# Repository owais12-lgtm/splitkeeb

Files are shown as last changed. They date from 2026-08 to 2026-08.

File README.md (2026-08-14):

This my 42 key wireless split keyboard! It follows the corne layout I believe with a 3x6+3 layout. It will use 42 switches and a screen, and is powered by a custom made rp2040 dev board.

# pictures 







# Features
- Dual-core M0+ processor
- Flexible clock running up to 133 MHz
- 264 kB of SRAM
- USB 1.1 controller and PHY with device and host support
- Low-power sleep and dormant modes
- Accurate clock and timer
- Accelerated floating-point libraries
- Temperature sensor
- Oled screen

# BOM 

| Name | Purpose | Quantity | Total Cost (USD) | Link | Distributor |
|---|---|---|---|---|---|
| PCB | PCB | 1 | $60.00 | [lioncircuits.com](https://www.lioncircuits.com/quote) | Lion Circuits |
| Keycaps | Keycaps | 1 | $30.00 | [curiositycaps.in](https://curiositycaps.in/products/polar-day-line-crack-side-backlit-cherry-keycaps) | Curiosity Caps |
| Akko V3 Silver | Switches | 2 | $32.00 | [stackskb.com](https://stackskb.com/store/akko-v3-silver-pro-switch-pack-of-45/) | StacksKB |
| OLED | OLED | 1 | $2.00 | [robu.in](https://robu.in/product/0-91-inch-128x32-i2c-iic-serial-blue-oled-lcd-display-module/) | Robu |

# CAD
https://www.tinkercad.com/things/a4B1lVT00vB-epic-allis-leelo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

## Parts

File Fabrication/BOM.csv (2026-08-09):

Id | Designator | Footprint | Quantity | Designation | Supplier and ref
1 | D33,D27,D26,D28,D24,D30,D32,D31,D23,D29,D25,D22,D29,D23,D30,D33,D24,D26,D27,D25,D32,D31,D28,D22 | LED_0201_0603Metric | 24 | LED
2 | C14,C13,C14,C13 | C_0402_1005Metric | 4 | 33pF
3 | C8,C7,C2,C12,C11,C17,C10,C5,C9,C6,C3,C7,C5,C9,C2,C8,C10,C12,C11,C6,C3,C17 | C_0402_1005Metric | 22 | 0.1uF
4 | SW29,SW41,SW28,SW39,SW35,SW34,SW40,SW37,SW43,SW27,SW30,SW24,SW33,SW23,SW36,SW38,SW31,SW42,SW25,SW32,SW26,SW8,SW20,SW12,SW19,SW5,SW3,SW18,SW7,SW11,SW14,SW13,SW4,SW21,SW17,SW6,SW2,SW10,SW15,SW16,SW1,SW9 | SW_Cherry_MX_1.00u_PCB | 42 | SW_Push_45deg
5 | U2,U2 | SOT-23 | 2 | MCP1700x-330xxTT
6 | C1,C4,C4,C1 | C_0402_1005Metric | 4 | 1uF
7 | C16,C15,C16,C15 | C_0603_1608Metric | 4 | 10uF
8 | R2,R1,R2,R1 | R_0402_1005Metric | 4 | 27
9 | U1,U1 | QFN-56-1EP_7x7mm_P0.4mm_EP3.2x3.2mm | 2 | RP2040
10 | SW22,SW22 | SW_Push_SPST_NO_Alps_SKRK | 2 | SW_Push
11 | J1,J1 | USB_C_Receptacle_HRO_TYPE-C-31-M-12 | 2 | USB_C_Receptacle_USB2.0_14P
12 | R6,R3,R6,R3 | R_0402_1005Metric | 4 | 1K
13 | R7,R7 | R_0402_1005Metric | 2 | 10K
14 | R5,R4,R4,R5 | R_0402_1005Metric | 4 | 5.1K
15 | Y1,Y1 | Crystal_SMD_3225-4Pin_3.2x2.5mm | 2 | 12 MHz
16 | U3,U3 | Winbond_USON-8-1EP_3x2mm_P0.5mm_EP0.2x1.6mm | 2 | W25Q16JVUXIQ TR
17 | D43,D35,D50,D49,D45,D51,D36,D40,D47,D46,D39,D41,D54,D42,D52,D48,D44,D53,D37,D38,D34,D17,D19,D21,D3,D2,D12,D5,D16,D14,D20,D10,D7,D18,D4,D9,D13,D1,D8,D11,D15,D6 | D_DO-35_SOD27_P7.62mm_Horizontal | 42 | 1N4148

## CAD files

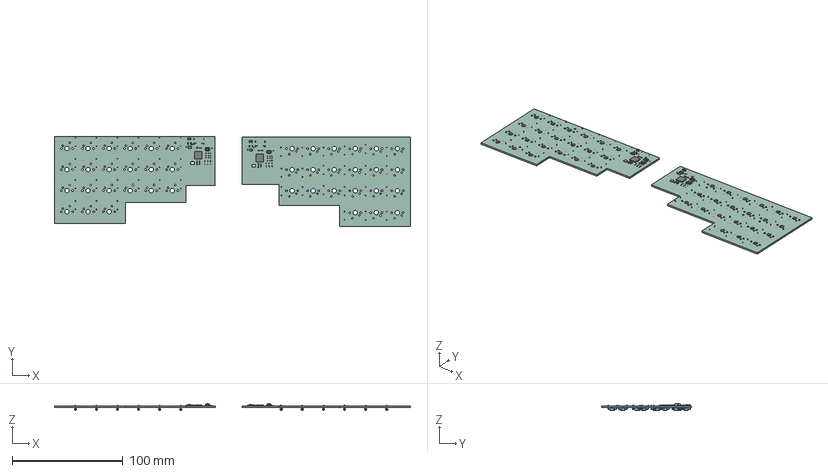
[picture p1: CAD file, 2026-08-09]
Fabrication/keeb.step
321.9 x 81.4 x 6.19 mm
R_0402_1005Metric x 14
LED_0201_0603Metric x 24
C_0402_1005Metric x 30
SOT-23 x 2
C_0603_1608Metric x 4
QFN-56-1EP_7x7mm_P0.4mm_EP3.2x3.2mm x 2
SW_Push_SPST_NO_Alps_SKRK x 2
Winbond_USON-8-1EP_3x2mm_P0.5mm_EP0.2x1.6mm x 2
Crystal_SMD_3225-4Pin_3.2x2.5mm x 2
D_DO-35_SOD27_P7.62mm_Horizontal x 42
dev-board_PCB_1
dev-board_PCB_2

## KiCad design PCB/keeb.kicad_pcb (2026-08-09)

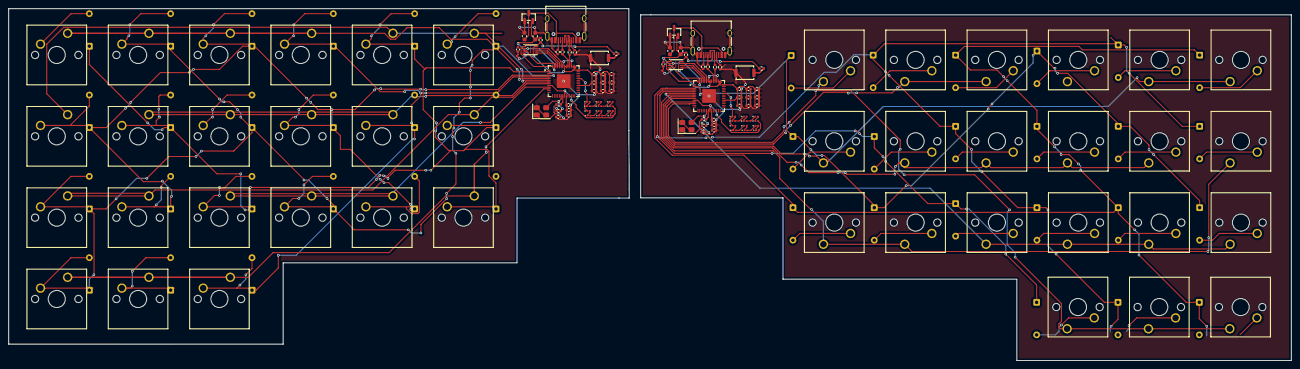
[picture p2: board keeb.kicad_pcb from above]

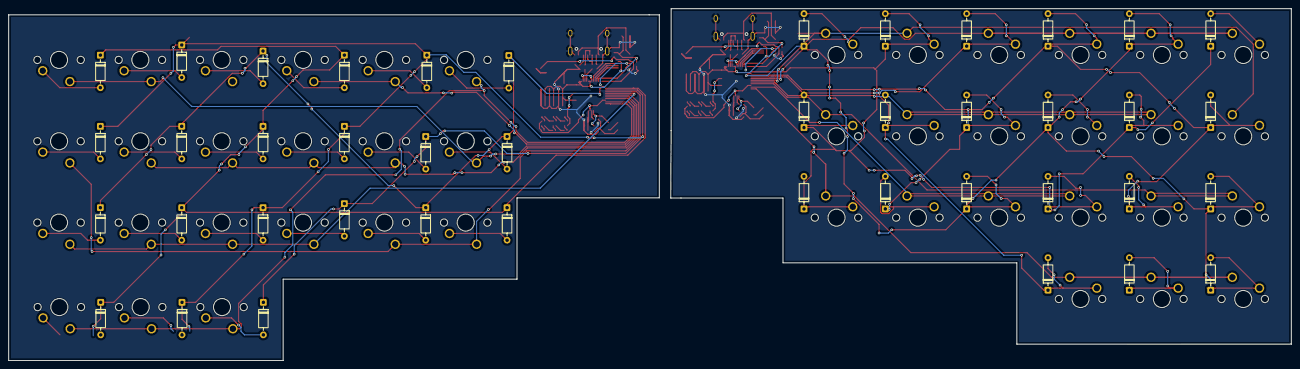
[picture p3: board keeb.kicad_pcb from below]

Board: 2 copper layers, 300.4 x 82.4 mm, 168 parts (42 on the bottom side), 103 nets.

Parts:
C1, C1#2, C4, C4#2: 1uF; C_0402_1005Metric
C2, C2#2, C3, C3#2, C5, C5#2, C6, C6#2, C7, C7#2, C8, C8#2, C9, C9#2, C10, C10#2, C11, C11#2, C12, C12#2, C17, C17#2: 0.1uF; C_0402_1005Metric
C13, C13#2, C14, C14#2: 33pF; C_0402_1005Metric
C15, C15#2, C16, C16#2: 10uF; C_0603_1608Metric
D1, D2, D3, D4, D5, D6, D7, D8, D9, D10, D11, D12, D13, D14, D15, D16, D17, D18, D19, D20, D21, D34, D35, D36, D37, D38, D39, D40, D41, D42, D43, D44, D45, D46, D47, D48, D49, D50, D51, D52, D53, D54: 1N4148; D_DO-35_SOD27_P7.62mm_Horizontal
D22, D22#2, D23, D23#2, D24, D24#2, D25, D25#2, D26, D26#2, D27, D27#2, D28, D28#2, D29, D29#2, D30, D30#2, D31, D31#2, D32, D32#2, D33, D33#2: LED; LED_0201_0603Metric
J1, J1#2: USB_C_Receptacle_USB2.0_14P; USB_C_Receptacle_HRO_TYPE-C-31-M-12
R1, R1#2, R2, R2#2: 27; R_0402_1005Metric
R3, R3#2, R6, R6#2: 1K; R_0402_1005Metric
R4, R4#2, R5, R5#2: 5.1K; R_0402_1005Metric
R7, R7#2: 10K; R_0402_1005Metric
SW1, SW2, SW3, SW4, SW5, SW6, SW7, SW8, SW9, SW10, SW11, SW12, SW13, SW14, SW15, SW16, SW17, SW18, SW19, SW20, SW21, SW23, SW24, SW25, SW26, SW27, SW28, SW29, SW30, SW31, SW32, SW33, SW34, SW35, SW36, SW37, SW38, SW39, SW40, SW41, SW42, SW43: SW_Push_45deg; SW_Cherry_MX_1.00u_PCB
SW22, SW22#2: SW_Push; SW_Push_SPST_NO_Alps_SKRK
U1, U1#2: RP2040; QFN-56-1EP_7x7mm_P0.4mm_EP3.2x3.2mm
U2, U2#2: MCP1700x-330xxTT; SOT-23
U3, U3#2: W25Q16JVUXIQ TR; Winbond_USON-8-1EP_3x2mm_P0.5mm_EP0.2x1.6mm
Y1, Y1#2: 12 MHz; Crystal_SMD_3225-4Pin_3.2x2.5mm

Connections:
+1V1: C1.1, C1#2.1, C2.1, C2#2.1, C3.1, C3#2.1, U1.23 (DVDD), U1.45 (VREG_VOUT), U1.50 (DVDD), U1#2.23 (DVDD), U1#2.45 (VREG_VOUT), U1#2.50 (DVDD)
+3V3: C4.1, C4#2.1, C5.1, C5#2.1, C6.1, C6#2.1, C7.1, C7#2.1, C8.1, C8#2.1, C9.1, C9#2.1, C10.1, C10#2.1, C11.1, C11#2.1, C12.1, C12#2.1, C16.1, C16#2.1, C17.1, C17#2.1, D32.2 (A), D32#2.2 (A), D33.2 (A), D33#2.2 (A), R7.2, R7#2.2, U1.1 (IOVDD), U1.10 (IOVDD), U1.22 (IOVDD), U1.33 (IOVDD), U1.42 (IOVDD), U1.43 (ADC_AVDD), U1.44 (VREG_IN), U1.48 (USB_VDD), U1.49 (IOVDD), U1#2.1 (IOVDD), U1#2.10 (IOVDD), U1#2.22 (IOVDD), U1#2.33 (IOVDD), U1#2.42 (IOVDD), U1#2.43 (ADC_AVDD), U1#2.44 (VREG_IN), U1#2.48 (USB_VDD), U1#2.49 (IOVDD), U2.2 (VO), U2#2.2 (VO), U3.8 (VCC), U3#2.8 (VCC)
Col0: SW1.1, SW2.1, SW3.1, SW4.1, SW23.1, SW24.1, SW25.1, SW26.1, U1.6 (GPIO4), U1#2.6 (GPIO4)
Col1: SW5.1, SW6.1, SW7.1, SW27.1, SW28.1, SW29.1, U1.7 (GPIO5), U1#2.7 (GPIO5)
Col2: SW8.1, SW9.1, SW10.1, SW11.1, SW30.1, SW31.1, SW32.1, SW33.1, U1.8 (GPIO6), U1#2.8 (GPIO6)
Col3: SW12.1, SW13.1, SW14.1, SW34.1, SW35.1, SW36.1, U1.9 (GPIO7), U1#2.9 (GPIO7)
Col4: SW15.1, SW16.1, SW17.1, SW37.1, SW38.1, SW39.1, U1.11 (GPIO8), U1#2.11 (GPIO8)
Col5: SW18.1, SW19.1, SW20.1, SW21.1, SW40.1, SW41.1, SW42.1, SW43.1, U1.12 (GPIO9), U1#2.12 (GPIO9)
GND: C1.2, C1#2.2, C2.2, C2#2.2, C3.2, C3#2.2, C4.2, C4#2.2, C5.2, C5#2.2, C6.2, C6#2.2, C7.2, C7#2.2, C8.2, C8#2.2, C9.2, C9#2.2, C10.2, C10#2.2, C11.2, C11#2.2, C12.2, C12#2.2, C13.1, C13#2.1, C14.1, C14#2.1, C15.2, C15#2.2, C16.2, C16#2.2, C17.2, C17#2.2, J1.A1 (GND), J1.A12 (GND), J1.B1 (GND), J1.B12 (GND), J1.S1 (SHIELD), J1#2.A1 (GND), J1#2.A12 (GND), J1#2.B1 (GND), J1#2.B12 (GND), J1#2.S1 (SHIELD), R4.2, R4#2.2, R5.2, R5#2.2, SW22.1, SW22#2.1, U1.57 (GND), U1#2.57 (GND), U2.1 (GND), U2#2.1 (GND), U3.4 (GND), U3#2.4 (GND), Y1.2, Y1.4, Y1#2.2, Y1#2.4
GPIO11: U1.14 (GPIO11), U1#2.14 (GPIO11)
GPIO12: U1.15 (GPIO12), U1#2.15 (GPIO12)
GPIO13: U1.16 (GPIO13), U1#2.16 (GPIO13)
GPIO14: U1.17 (GPIO14), U1#2.17 (GPIO14)
GPIO15: U1.18 (GPIO15), U1#2.18 (GPIO15)
GPIO16: U1.27 (GPIO16), U1#2.27 (GPIO16)
GPIO17: U1.28 (GPIO17), U1#2.28 (GPIO17)
GPIO18: U1.29 (GPIO18), U1#2.29 (GPIO18)
GPIO19: U1.30 (GPIO19), U1#2.30 (GPIO19)
GPIO20: U1.31 (GPIO20), U1#2.31 (GPIO20)
GPIO21: U1.32 (GPIO21), U1#2.32 (GPIO21)
GPIO22: U1.34 (GPIO22), U1#2.34 (GPIO22)
GPIO23: U1.35 (GPIO23), U1#2.35 (GPIO23)
GPIO24: U1.36 (GPIO24), U1#2.36 (GPIO24)
GPIO26_ADC0: U1.38 (GPIO26_ADC0), U1#2.38 (GPIO26_ADC0)
GPIO27_ADC1: U1.39 (GPIO27_ADC1), U1#2.39 (GPIO27_ADC1)
GPIO28_ADC2: U1.40 (GPIO28_ADC2), U1#2.40 (GPIO28_ADC2)
GPIO29_ADC3: U1.41 (GPIO29_ADC3), U1#2.41 (GPIO29_ADC3)
unnamed: C14.2, C14#2.2, R3.1, R3#2.1, Y1.1, Y1#2.1
unnamed: D1.2 (A), SW1.2
unnamed: D2.2 (A), SW2.2
unnamed: D3.2 (A), SW3.2
unnamed: D4.2 (A), SW4.2
unnamed: D5.2 (A), SW5.2
unnamed: D6.2 (A), SW6.2
unnamed: D7.2 (A), SW7.2
unnamed: D8.2 (A), SW8.2
unnamed: D9.2 (A), SW9.2
unnamed: D10.2 (A), SW10.2
unnamed: D11.2 (A), SW11.2
unnamed: D12.2 (A), SW12.2
unnamed: D13.2 (A), SW13.2
unnamed: D14.2 (A), SW14.2
unnamed: D15.2 (A), SW15.2
unnamed: D16.2 (A), SW16.2
unnamed: D17.2 (A), SW17.2
unnamed: D18.2 (A), SW18.2
unnamed: D19.2 (A), SW19.2
unnamed: D20.2 (A), SW20.2
unnamed: D21.2 (A), SW21.2
unnamed: D22.2 (A), D22#2.2 (A), D24.1 (K), D24#2.1 (K)
unnamed: D22.1 (K), D22#2.1 (K), D23.1 (K), D23#2.1 (K), U1.37 (GPIO25), U1#2.37 (GPIO25)
unnamed: D23.2 (A), D23#2.2 (A), D25.1 (K), D25#2.1 (K)
unnamed: D24.2 (A), D24#2.2 (A), D26.1 (K), D26#2.1 (K)
unnamed: D25.2 (A), D25#2.2 (A), D27.1 (K), D27#2.1 (K)
unnamed: D26.2 (A), D26#2.2 (A), D28.1 (K), D28#2.1 (K)
unnamed: D27.2 (A), D27#2.2 (A), D29.1 (K), D29#2.1 (K)
unnamed: D28.2 (A), D28#2.2 (A), D30.1 (K), D30#2.1 (K)
unnamed: D29.2 (A), D29#2.2 (A), D31.1 (K), D31#2.1 (K)
unnamed: D30.2 (A), D30#2.2 (A), D32.1 (K), D32#2.1 (K)
unnamed: D31.2 (A), D31#2.2 (A), D33.1 (K), D33#2.1 (K)
unnamed: D34.2 (A), SW23.2
unnamed: D35.2 (A), SW24.2
unnamed: D36.2 (A), SW25.2
unnamed: D37.2 (A), SW26.2
unnamed: D38.2 (A), SW27.2
unnamed: D39.2 (A), SW28.2
unnamed: D40.2 (A), SW29.2
unnamed: D41.2 (A), SW30.2
unnamed: D42.2 (A), SW31.2
unnamed: D43.2 (A), SW32.2
unnamed: D44.2 (A), SW33.2
unnamed: D45.2 (A), SW34.2
unnamed: D46.2 (A), SW35.2
unnamed: D47.2 (A), SW36.2
unnamed: D48.2 (A), SW37.2
unnamed: D49.2 (A), SW38.2
unnamed: D50.2 (A), SW39.2
unnamed: D51.2 (A), SW40.2
unnamed: D52.2 (A), SW41.2
unnamed: D53.2 (A), SW42.2
unnamed: D54.2 (A), SW43.2
unnamed: J1.A5 (CC1), J1#2.A5 (CC1), R4.1, R4#2.1
unnamed: J1.B5 (CC2), J1#2.B5 (CC2), R5.1, R5#2.1
unnamed: R6.2, R6#2.2, SW22.2, SW22#2.2
unnamed: R2.2, R2#2.2, U1.46 (USB_DM), U1#2.46 (USB_DM)
unnamed: R1.2, R1#2.2, U1.47 (USB_DP), U1#2.47 (USB_DP)
QSPI_SCLK: U1.52 (QSPI_SCLK), U1#2.52 (QSPI_SCLK), U3.6 (CLK), U3#2.6 (CLK)
QSPI_SD0: U1.53 (QSPI_SD0), U1#2.53 (QSPI_SD0), U3.5 (DI/IO_{0}), U3#2.5 (DI/IO_{0})
QSPI_SD1: U1.55 (QSPI_SD1), U1#2.55 (QSPI_SD1), U3.2 (DO/IO_{1}), U3#2.2 (DO/IO_{1})
QSPI_SD2: U1.54 (QSPI_SD2), U1#2.54 (QSPI_SD2), U3.3 (~WP/IO_{2}), U3#2.3 (~WP/IO_{2})
QSPI_SD3: U1.51 (QSPI_SD3), U1#2.51 (QSPI_SD3), U3.7 (~HOLD/~RESET/IO_{3}), U3#2.7 (~HOLD/~RESET/IO_{3})
QSPI_SS: R6.1, R6#2.1, R7.1, R7#2.1, U1.56 (QSPI_SS), U1#2.56 (QSPI_SS), U3.1 (~CS), U3#2.1 (~CS)
Row0: D1.1 (K), D5.1 (K), D8.1 (K), D12.1 (K), D15.1 (K), D18.1 (K), D34.1 (K), D38.1 (K), D41.1 (K), D45.1 (K), D48.1 (K), D51.1 (K), U1.2 (GPIO0), U1#2.2 (GPIO0)
Row1: D2.1 (K), D6.1 (K), D9.1 (K), D13.1 (K), D16.1 (K), D19.1 (K), D35.1 (K), D39.1 (K), D42.1 (K), D46.1 (K), D49.1 (K), D52.1 (K), U1.3 (GPIO1), U1#2.3 (GPIO1)
Row2: D3.1 (K), D7.1 (K), D10.1 (K), D14.1 (K), D17.1 (K), D20.1 (K), D36.1 (K), D40.1 (K), D43.1 (K), D47.1 (K), D50.1 (K), D53.1 (K), U1.4 (GPIO2), U1#2.4 (GPIO2)
Row3: D4.1 (K), D11.1 (K), D21.1 (K), D37.1 (K), D44.1 (K), D54.1 (K), U1.5 (GPIO3), U1#2.5 (GPIO3)
SWCLK: U1.24 (SWCLK), U1#2.24 (SWCLK)
SWD: U1.25 (SWD), U1#2.25 (SWD)
USB_D+: J1.A6 (D+), J1.B6 (D+), J1#2.A6 (D+), J1#2.B6 (D+), R1.1, R1#2.1
USB_D-: J1.A7 (D-), J1.B7 (D-), J1#2.A7 (D-), J1#2.B7 (D-), R2.1, R2#2.1
VBUS: C15.1, C15#2.1, J1.A4 (VBUS), J1.A9 (VBUS), J1.B4 (VBUS), J1.B9 (VBUS), J1#2.A4 (VBUS), J1#2.A9 (VBUS), J1#2.B4 (VBUS), J1#2.B9 (VBUS), U2.3 (VI), U2#2.3 (VI)
XIN: C13.2, C13#2.2, U1.20 (XIN), U1#2.20 (XIN), Y1.3, Y1#2.3
XOUT: R3.2, R3#2.2, U1.21 (XOUT), U1#2.21 (XOUT)

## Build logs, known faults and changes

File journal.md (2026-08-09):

# Total time: 42 hrs

## 10/6/26 - 3 hours
I worked on the schematic for the split keyboard, I made my switch matrix for both sides. One of the problems I had with this and why it took way longer than I thought it would was that the symbols for choc switches got deleted from my laptop so I had to find where I got those from initially.

 

---

## 13/6/26 - 6 hours
I made part of my dev board schematic, I used Kai Pererra's guide to make this. some of parts i messed up were the 8 IO VDD pins, and wiring the decoupling capacitors.i also had to replace the NCP1117 twice cuz both those were the wrong ones and had to be replaced 
 

I finished the other part of my dev board schematic, this one took way longer than I expected.



---

## 5/7/26 - 5 hours
This PCB is so annoying to place, all these switches seem to be at the wrong place with traces going through them that shouldn't be and the diodes are inside the switches, I gotta manually fix all those cuz I'm dumb.

 



---

## 11/7/26 - 6 hours
I'm working on the placement for this dev board, I wanna try making it as compact as possible but I might have no choice but to make it spaced out. This routing is gonna kill me why does this dev board not wanna work, it seems to be insanely difficult to route this to be pretty smol. I also went ahead and replaced all the diodes cuz they were inside the keys and some of them were wrong too.

 

 



---

## 13/7/26 - 6 hours
I spent most of this journal trying to route this shitty ahh PCB, the placement of the keys is in like diagonal and that makes routes worse, cuz I need to route everything diagonally. The dev board too seems to have some issues I increased the spacing between some of these connections. I spent a while reading thru Kai's guide. I've made this before but I don't think that one would've worked.

Screenshot from 2026-07-13 19-33-24 Screenshot from 2026-07-13 18-51-01

Screenshot from 2026-07-13 21-24-02 Screenshot from 2026-07-13 21-12-36

Screenshot from 2026-07-13 21-12-20 Screenshot from 2026-07-13 20-19-04

---

## 15/7/26 - 1 hour
So yummy routing I love routing so fun /s how the hell did this take me 2 hrs to do it cannot be that hard :pray-sob:



---

## 16/7/26 - 5 hours
I did a whoopsi and yet again put these diodes at the wrong place yay, so now I have to move every one of these left and down. Now for the routing, this is all diagonal so I gotta do that bit again cuz a lot of these connections seem to have been messed up after I moved the diodes. This is prolly the final routing for this side of the split keeb! I should be done with the dev board part of this soon too. It's prolly gonna be copying and pasting the other one and adding a few changes.

Screenshot from 2026-07-16 17-31-29 

 

---

## 17/7/26 - 3 hours
For this journal entry I spent most of my morning trying to route my dev board, this is how far I got without DRC ruining it for me. I finished routing the entire thing so I can now fix all the errors and stuff DRC shows me along with the malformed boundary so I can start work on my case.

Screenshot from 2026-07-17 15-40-30 Screenshot from 2026-07-17 15-35-49

# drc errors
my drc errors r so fried its insane im gonna fix all of these hopefully. its a mix of clearence errors and traces crossing each other + shorted nets + malformed outlines + solder masks touch the other nets. 

i got all of these fixed and am now only left with unconnected items which i can ignore cuz its a kicad error and not a actual problem

time spent: 4 hours









# case

i spent 1 hour on this pretty bad case made in tinkercad, its so bad its amazing but uh it works and thats what matters 😭



https://www.tinkercad.com/things/a4B1lVT00vB-epic-allis-leelo

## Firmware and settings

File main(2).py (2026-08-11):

import board
import busio
from kmk.kmk_keyboard import KMKKeyboard
from kmk.keys import KC
from kmk.scanners import DiodeOrientation
from kmk.modules.layers import Layers
from kmk.modules.encoder import EncoderHandler
from kmk.extensions.media_keys import MediaKeys
from kmk.modules.oled import Oled, OledData

keyboard = KMKKeyboard()

keyboard.row_pins = (
    board.GP0,
    board.GP1,
    board.GP2,
    board.GP3,
    board.GP4,
    board.GP5,
)

keyboard.col_pins = (
    board.GP6,
    board.GP7,
    board.GP8,
    board.GP9,
    board.GP10,
    board.GP11,
    board.GP12,
    board.GP13,
    board.GP14,
    board.GP15,
    board.GP16,
    board.GP17,
    board.GP18,
    board.GP19,
    board.GP20,
    board.GP21,
)

keyboard.diode_orientation = DiodeOrientation.COL2ROW

keyboard.modules.append(Layers())
keyboard.extensions.append(MediaKeys())

encoder_handler = EncoderHandler()
encoder_handler.pins = ((board.GP22, board.GP28, None),)
keyboard.modules.append(encoder_handler)

oled = Oled(
    OledData(
        corner_one={0: OledData.oled_text_entry(text="Layer: BASE", x=0, y=0)},
        corner_two={0: OledData.oled_text_entry(text="KMK Ready", x=0, y=16)},
    ),
    toDisplay=OledData.LAYER,
    i2c=lambda: busio.I2C(board.GP27, board.GP26),
)
keyboard.modules.append(oled)

___ = KC.TRNS

BASE = (
    KC.ESC,  KC.F1,   KC.F2,   KC.F3,   KC.F4,   KC.F5,   KC.F6,   KC.F7,   KC.F8,   KC.F9,   KC.F10,  KC.F11,  KC.F12,  KC.PSCR, KC.MUTE, KC.MPLY,
    KC.GRV,  KC.N1,   KC.N2,   KC.N3,   KC.N4,   KC.N5,   KC.N6,   KC.N7,   KC.N8,   KC.N9,   KC.N0,   KC.MINS, KC.EQL,  KC.BSPC, ___,     KC.DEL,
    KC.TAB,  KC.Q,    KC.W,    KC.E,    KC.R,    KC.T,    KC.Y,    KC.U,    KC.I,    KC.O,    KC.P,    KC.LBRC, KC.RBRC, KC.BSLS, ___,     KC.PGUP,
    KC.CAPS, KC.A,    KC.S,    KC.D,    KC.F,    KC.G,    KC.H,    KC.J,    KC.K,    KC.L,    KC.SCLN, KC.QUOT, ___,     KC.ENT,  ___,     KC.PGDN,
    KC.LSFT, ___,     KC.Z,    KC.X,    KC.C,    KC.V,    KC.B,    KC.N,    KC.M,    KC.COMM, KC.DOT,  KC.SLSH, ___,     KC.RSFT, KC.UP,   ___,
    KC.LCTL, KC.LGUI, KC.LALT, ___,     ___,     ___,     KC.SPC,  ___,     ___,     ___,     KC.RALT, KC.MO(1),KC.RCTL, KC.LEFT, KC.DOWN, KC.RGHT,
)

FN = (
    ___,     KC.BRID, KC.BRIU, KC.MCTL, ___,     ___,     ___,     KC.MPRV, KC.MPLY, KC.MNXT, KC.MUTE, KC.VOLD, KC.VOLU,
)

keyboard.keymap = [BASE, FN]

encoder_handler.map = (
    ((KC.VOLU, KC.VOLD),),
    ((KC.BRIU, KC.BRID),),
)

if __name__ == "__main__":
    keyboard.go()
